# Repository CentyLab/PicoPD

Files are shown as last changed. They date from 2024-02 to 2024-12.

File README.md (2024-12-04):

# PicoPD
Pico PD is a development board for USB Power Delivery development with Raspberry Pi Pico footprint. The board can help you negotiate voltage from USB PD 2.0, 3.0, and 3.1 with PPS (programable power supply) up to 5A of current at 20V max. The board feature input current/voltage/temperture reading as well as power switch to cut of the current to external devices.

# Quick links
[AP33772 Library](https://github.com/CentyLab/AP33772-Cpp)

[PicoPD Pinout](#picopd-pinout)

[Setup for AP33772 objects](#setup-for-ap33772-objects)

[Basic AP33772 functions](#basic-ap33772-functions)

[Important note](#important-note)

[Arduino IDE setup](#arduino-ide-setup)

[VSCode PlatformIO setup](#vscode-platformio-setup)

[Enable Serial print for debugging](#enable-serial-debug)

# Pin out
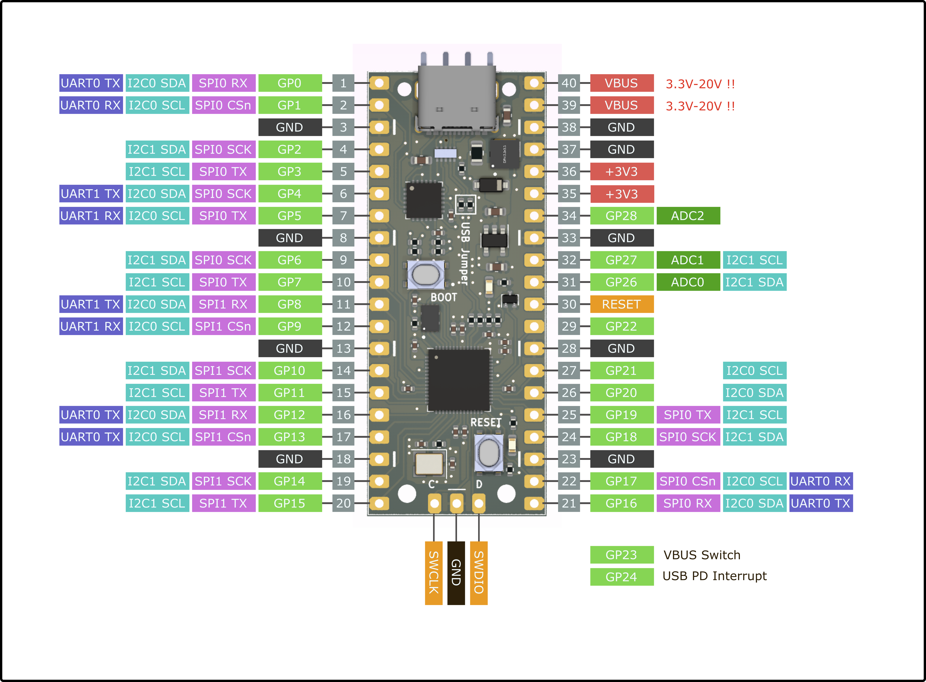
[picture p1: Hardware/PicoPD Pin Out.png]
pinout


# Setup for AP33772 objects
To use AP33772 IC with the library, first you need to create a `usbpd` object. Then set up your I2C pins and start collecting the power profiles from your charger. Ensure your delay after `Wire.begin()` is more than 500ms for stable PDOs request. Enable pin 23 to allow VBUS pass-through.
```
AP33772 usbpd; // Automatically wire to Wire0

void setup()
{
  Wire.setSDA(0); // Set the correct SDA0 pin
  Wire.setSCL(1); // Set the correct SCL0 pin
  Wire.begin();
  Serial.begin(115200);
  delay(1000); 		// Delay is needed for the IC to obtain PDOs
  usbpd.begin(); 	// Start pulling the PDOs from power supply

  pinMode(25, OUTPUT); // Built in LED
  pinMode(23, OUTPUT); // Load Switch
  digitalWrite(23, HIGH); // Turn on VBUS pin

  usbpd.printPDO(); //Print out PDO to Serial port
}
```

# Basic AP33772 functions
Common functions are:
```
setVoltage(int targetVoltage)       //Set voltage, unit in mV, read libary for logic flow
setMaxCurrent(int targetMaxCurrent) //Allow current limit if source has that capability
readVoltage()                       //Return voltage in mV
readCurrent()                       //Return current in mA
printPDO()                          //Print out PDOs in Serial
```

Set over tempearture protection
```
usbpd.setOTPTHR(100);               //Turn off output if NTC detect 100C or above
usbpd.setMask(OTP_EN);              //Enable Over Temp Protection flag
```

# Important note
After flashing, the latest AP33772-CPP has been updated to auto request PDO after bootup without reconnecting the charger. Thank to @Patronics contribution.

Calling `usbpd.printPDO()` without `Serial.begin()` can soft-brick your PicoPD. Causing the IC to be non-recognizable by your computer. You will have to use PicoProbe to reflash the chip. Check out @Patronics [PicoProbePCB](https://github.com/Patronics/PicoProbePCB) if you would like to make a stable fixture for firmware debugging.

# Enable Serial Debug

To enable Serial debug, there are 3 main methods:

**Using USB-C Power/Data splitter (easiest):** Use a USB-C Splitter that separates the USB 2.0 signal into another USB-C port. You only need USB 2.0 FullSpeed (12Mbps) for the job, but never hurts to get extra speed if needed later. 

* [USB-C Power/Data Splitter](https://lectronz.com/products/usb-c-splitter) (USB-HighSpeed)
* [USB-C PD Power Splitter](https://www.tindie.com/products/essenceeng/usb-c-pd-power-splitter/) (USB-HighSpeed)

**Using the provided solder pads at the back:** Desolder the front "USB Jumper" resistors. They are just 2x 0 Ohm resistors that bridge between the RP2040 IC and the USB-C port. Then use a [USB Type A Plug Breakout Cable](https://www.adafruit.com/product/4448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), or make your own from any USB cable and connect to the existing pad at the back of PicoPD

<p align="center">
  
</p>
<p align="center">
  
</p>

**Using UART communication**: Make sure you are not using GP0 and GP1 as they are reserved for I2C0 channel for AP33772 IC. Check out Youtube tutorial: [Talk to Your Pico Over Serial](https://www.youtube.com/watch?v=pbWhoJdYA1s)

# Arduino IDE setup
Open Arduino IDE, select File -> Preference
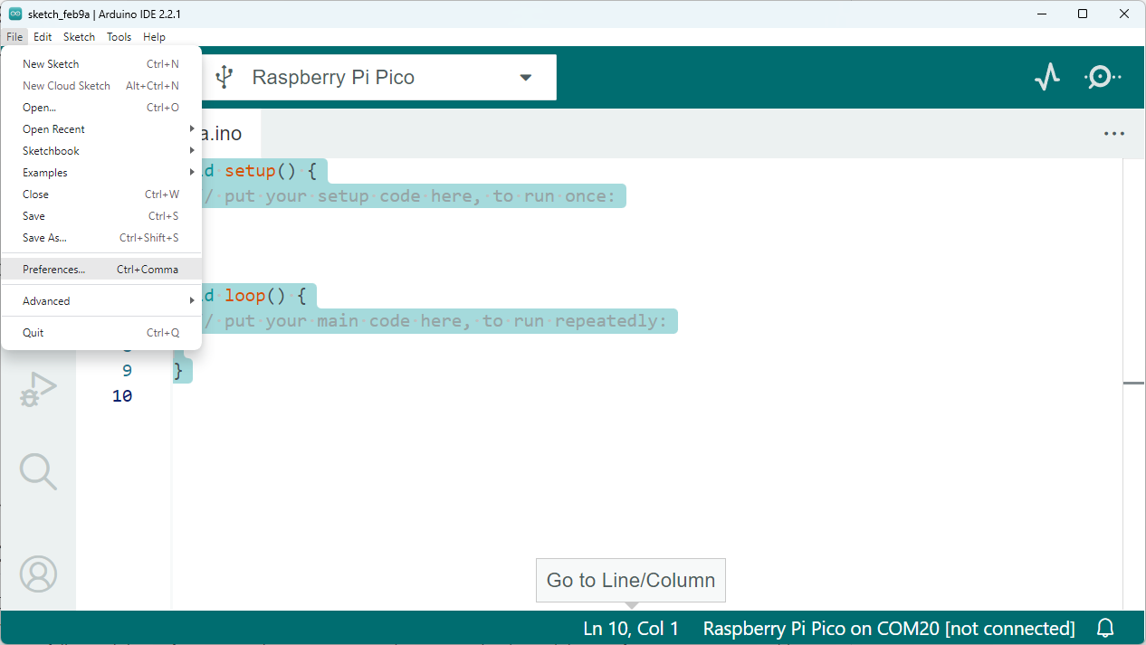
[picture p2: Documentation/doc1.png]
Preference


Copy this line below and place in "Aditional Boards Manager URLs" -> OK. This will allow you to pull the Earlephilhower Pico core that work with the AP33772 library.

```
https://github.com/earlephilhower/arduino-pico/releases/download/global/package_rp2040_index.json
```
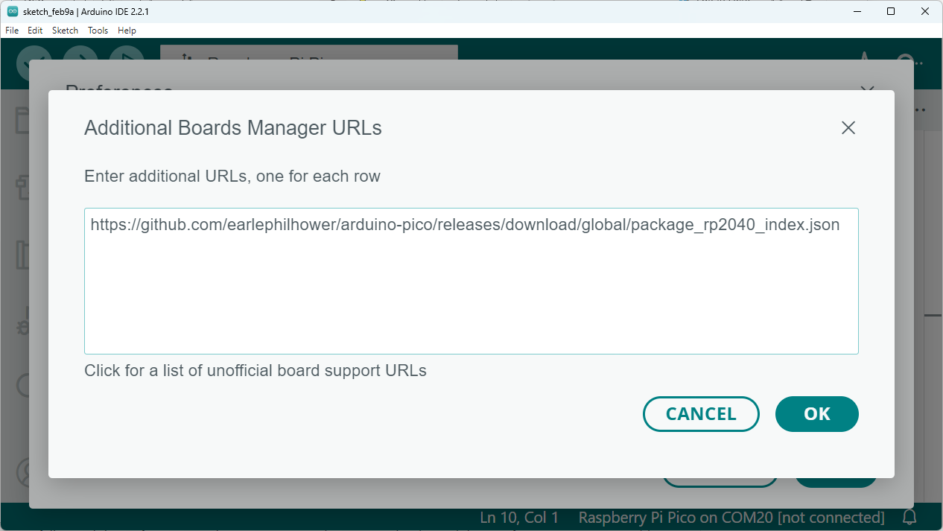
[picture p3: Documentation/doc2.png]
boardmanagerURL


From Board Manager, search for "Pico" and install the "Raspberry Pi Pico/RP2040" core by Earlephilhower

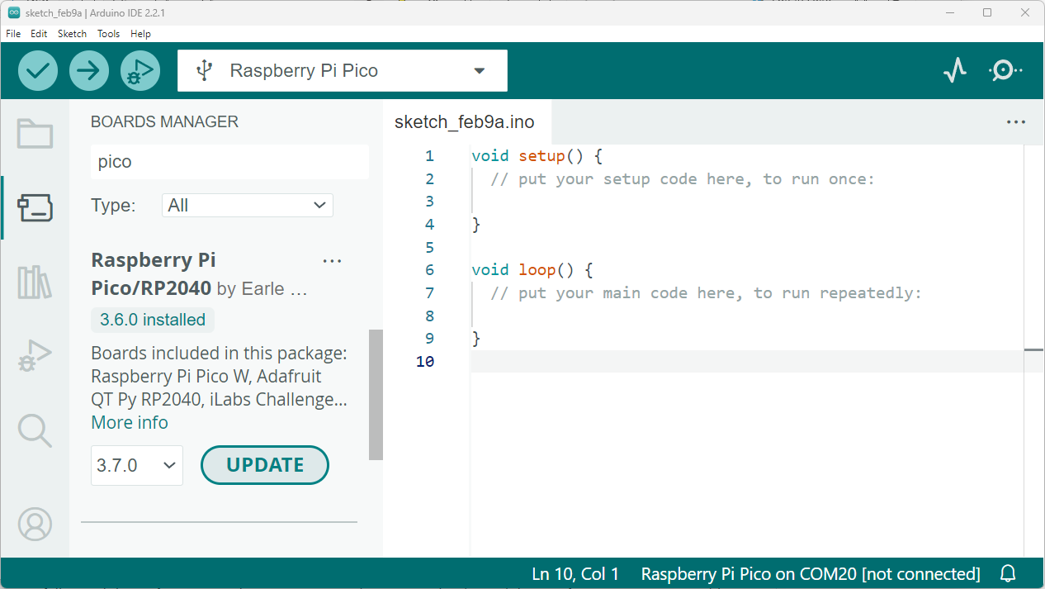
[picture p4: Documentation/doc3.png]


Now from Tool -> Board -> Raspberry Pi Pico/RP2040 -> Raspberry Pi Pico

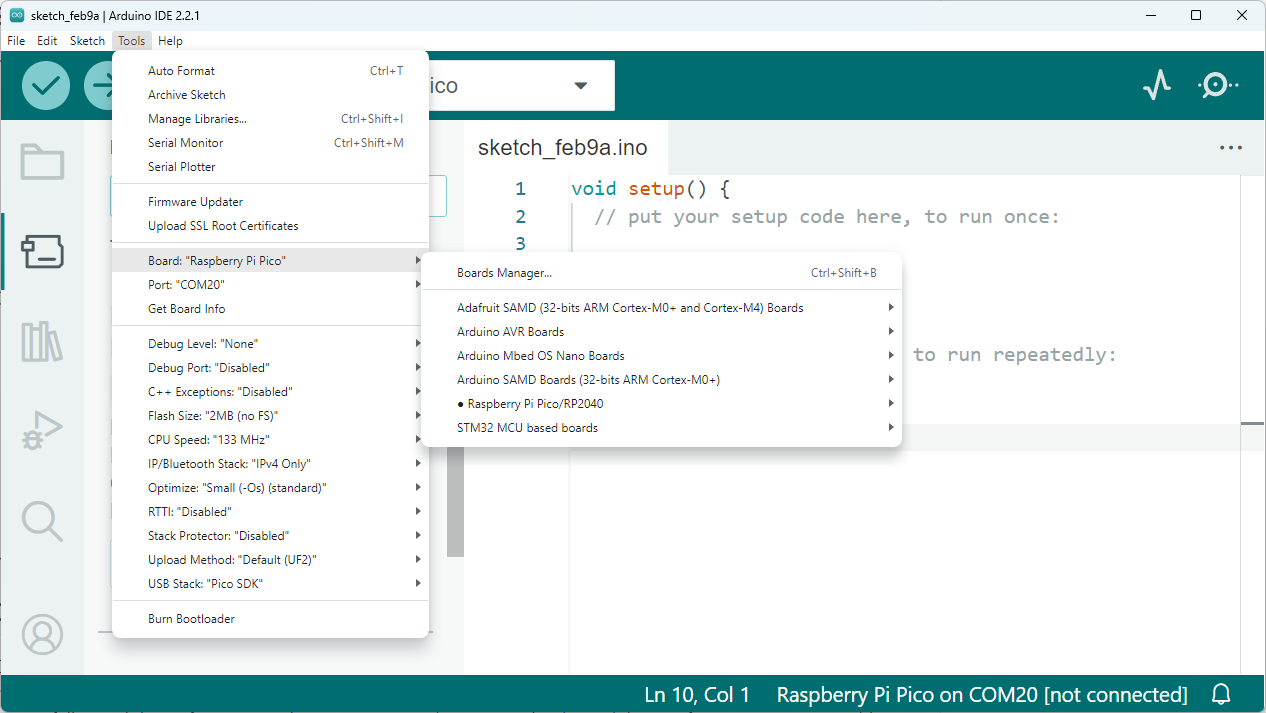
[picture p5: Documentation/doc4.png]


Now download the latest AP33772 library as a Zip file

```
https://github.com/CentyLab/AP33772-Cpp
```
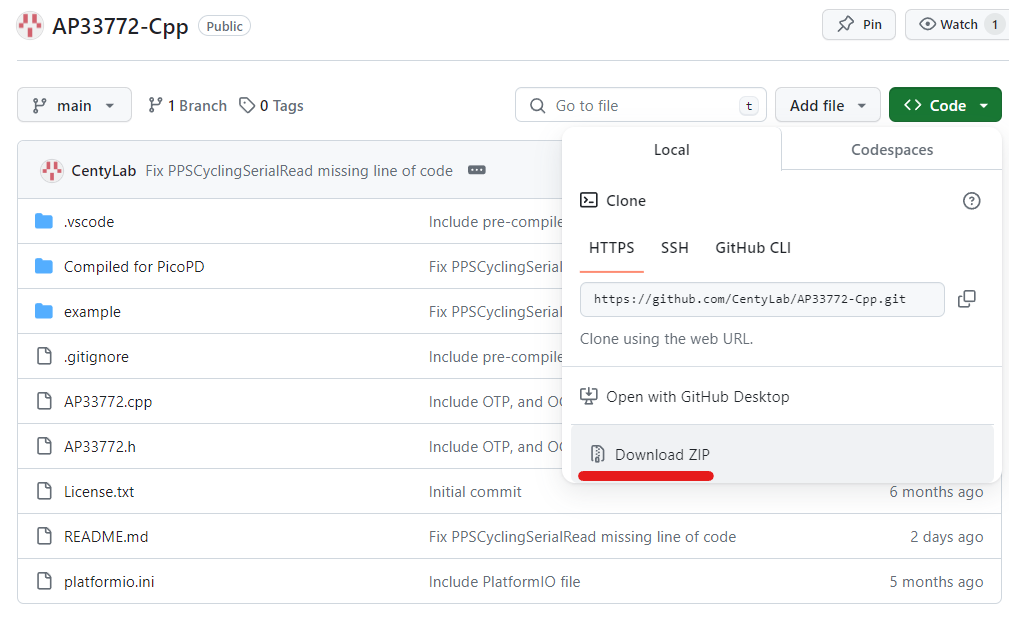
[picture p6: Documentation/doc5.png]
ap33772lib


Import the AP33772 library into your Arduino IDE. Sketch -> Include library -> Add .ZIP Library ...

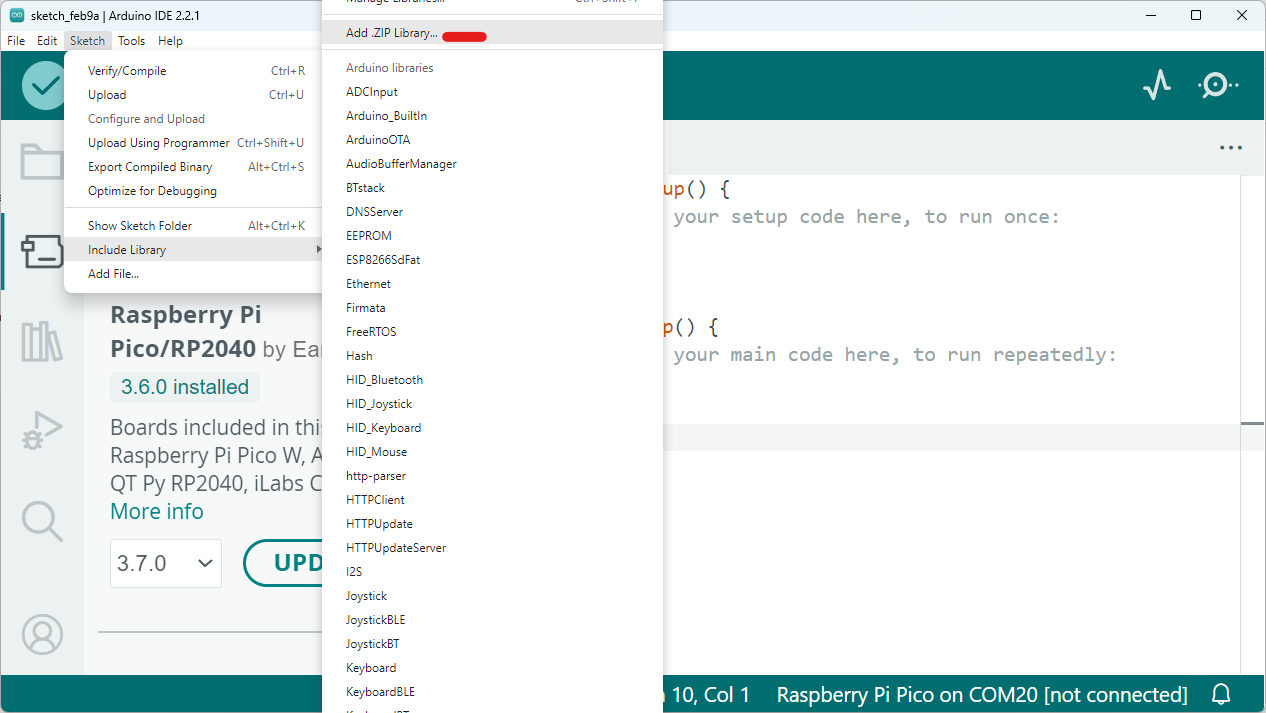
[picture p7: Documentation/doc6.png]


Now you start using the Example code in File -> Examples -> AP33772-Cpp-main. The example is ready to compile and flash on to your PicoPD.
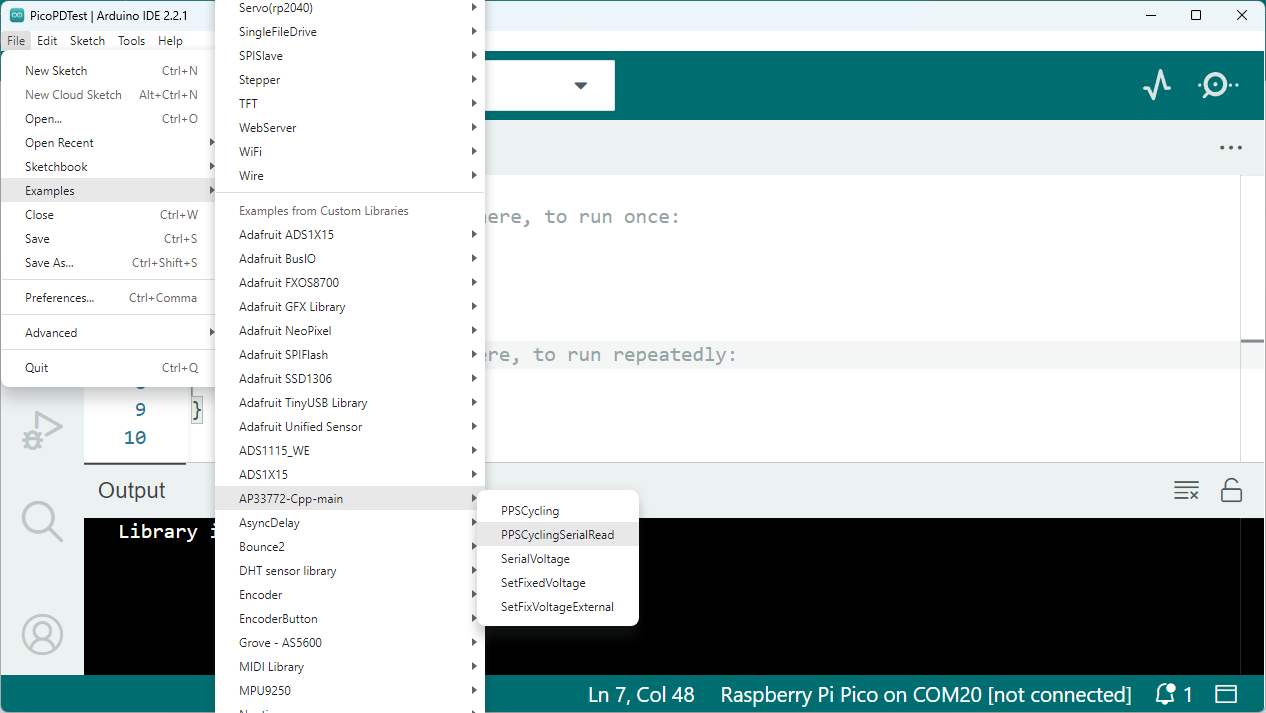
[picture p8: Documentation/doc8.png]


Now you can plug in your USB-C cable with Power Delivery 2.0/3.0/3.1. If you also like to have serial print out, check out [Enable Serial print for debugging](#enable-serial-debug).

# VSCode PlatformIO setup
After [VSCode](https://code.visualstudio.com/) installation, you will need to install PlatformIO extension.

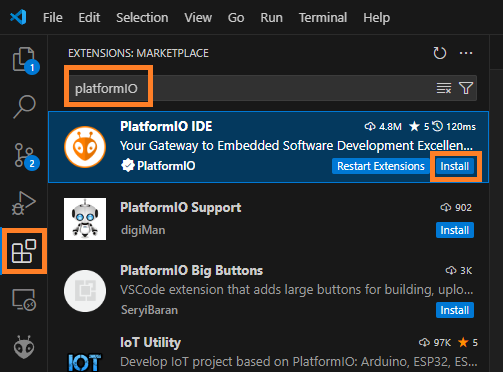
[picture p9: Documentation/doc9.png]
installplatform


Now create a new PlatformIO project
+ Name:WhatEverYouWantToCallit
+ Board: Pico (RasberryPi)
+ Framework: Arduino (default)

Click "Finish"

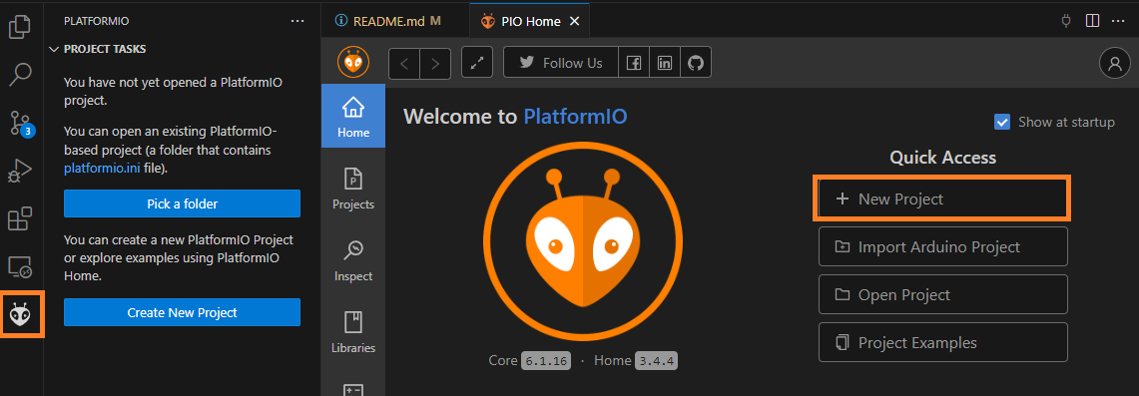
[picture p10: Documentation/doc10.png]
newproject


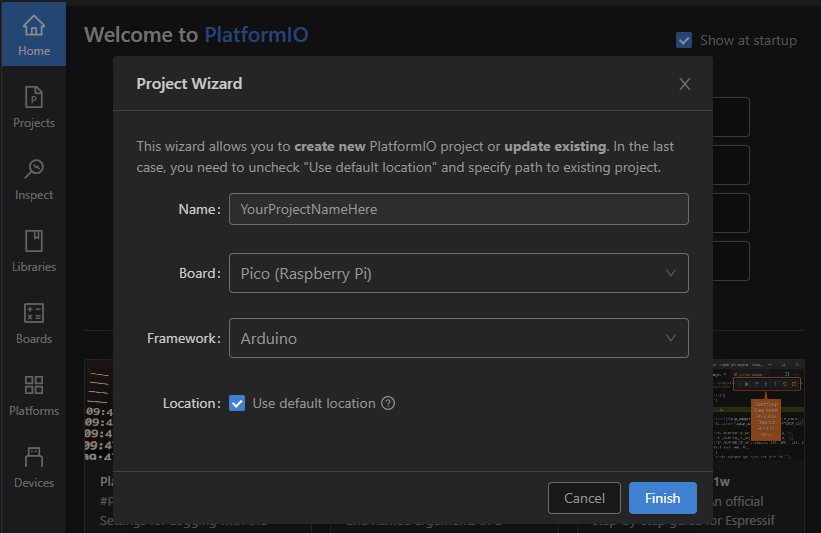
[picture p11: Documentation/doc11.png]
boardandframework


In your new project, copy this and replace everything in platformio.ini. This is how you ask PlatformIO to compile using Earlephilhower Pico core, and enable upload via USB.

```
[env:pico]
platform = https://github.com/maxgerhardt/platform-raspberrypi.git
board = pico
framework = arduino
board_build.core = earlephilhower

;; If directly upload from PC
upload_protocol = picotool
```

Now download the latest AP33772 library as a Zip file. Unzip and place the folder in `lib`

```
https://github.com/CentyLab/AP33772-Cpp
```

ap33772lib

Your lib folder should look like this

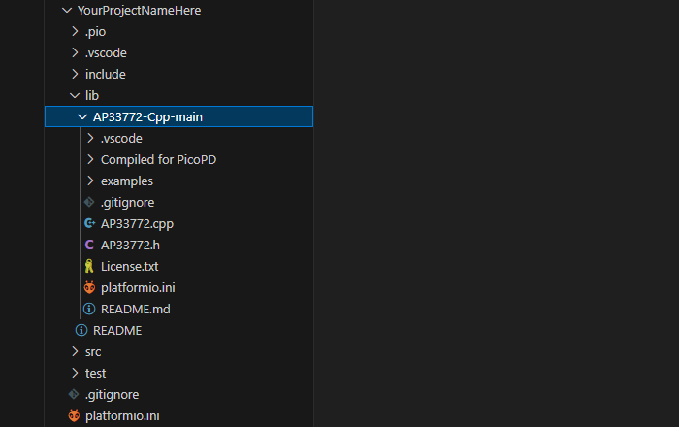
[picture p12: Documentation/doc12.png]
libstructur


To try out example code, you copy the content inside `lib/Compiled for PicoPD/PPSCycling/PPSCycling.ino`, And replace everything in your `src/main.cpp`

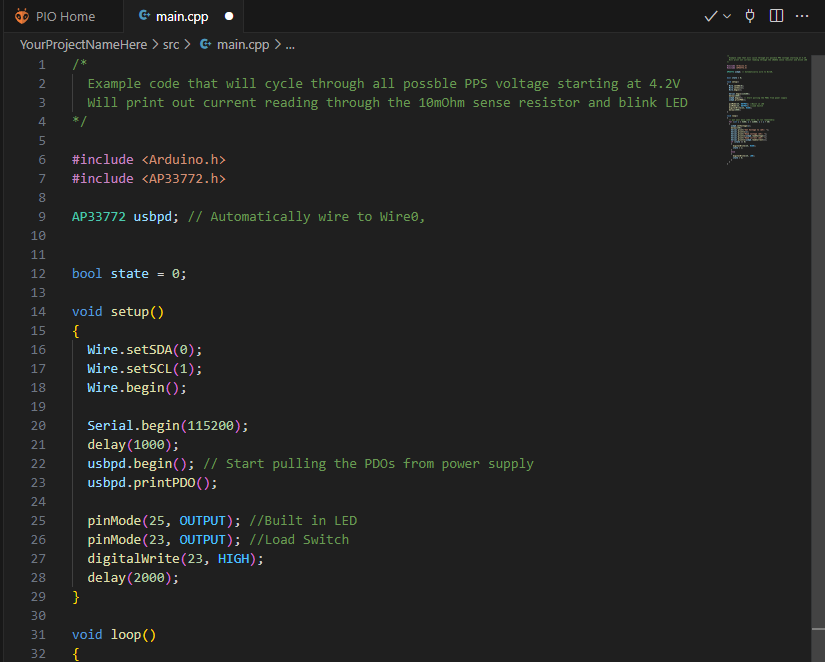
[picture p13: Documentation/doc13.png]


Now you can plug the PicoPD to your computer via USB-C and hit the upload button. After this, you will have to connect a charger to PicoPD to see the voltage cycling example. If you also like to have serial print out, check out [Enable Serial print for debugging](#enable-serial-debug).

maincpp

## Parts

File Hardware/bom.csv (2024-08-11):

Designator | Footprint | Quantity | Value | LCSC Part #
C10, C18, C2, C20, C21, C3, C4, C6, C7, C8, C9 | 0402 | 11 | 100nF | C1525
C11, C5 | 0402 | 2 | 2.2uF | C12530
C12 | 0603 | 1 | 1uF | C15849
C14 | 0603 | 1 | 2.2uF | C23630
C15, C22 | 0603 | 2 | 1u | C15849
C16, C17 | 0402 | 2 | 30pF | C1570
D1 | 0603 | 1 | RED | C2286
D2 | 0603 | 1 | GREEN | C72043
D3 | SON50P100X255X50-10N | 1 | TPD4E05U06DQAR | C138714
D4 | D_SOD-123 | 1 | D | C8598
J2 | YTC-TC16S-28 | 1 | USB_C_Receptacle | C2927293
Q2 | SOT-416 | 1 | DTC143EETL | C2991940
Q3 | TRANS_AON7403 | 1 | MSK3419DF | C2902915
R1, R16, R3, R4, R7 | 0402 | 5 | 5.1k | C25905
R10, R11 | 0402 | 2 | 27R | C138021
R12, R6 | 0402 | 2 | 10k | C25744
R13, R14, R17, R2 | 0402 | 4 | 1k | C11702
R18, R19 | 0402 | 2 | 0R | C17168
R5 | 0805 | 1 | 10mR | C728271
SW2 | SW_PTS810_SJM_250_SMTR_LFS | 1 | SW_RESET | C221896
SW4 | SW_PTS810_SJM_250_SMTR_LFS | 1 | SW_BOOT | C221896
TH1 | 0402 | 1 | Thermistor_NTC | C77131
U1 | QFN-24-1EP_4x4mm_P0.5mm_EP2.6x2.6mm | 1 | AP33772 | C5244513
U2 | IC_W25Q16JVUXIQ_TR | 1 | W25Q16JVUXIQ_TR | C2843335
U3 | QFN-56-1EP_7x7mm_P0.4mm_EP3.2x3.2mm | 1 | RP2040 | C2040
U4 | SOT-23-5 | 1 | AP2204K-3.3 | C112032
Y1 | Crystal_SMD_3225-4Pin_3.2x2.5mm | 1 | 12MHz | C133334

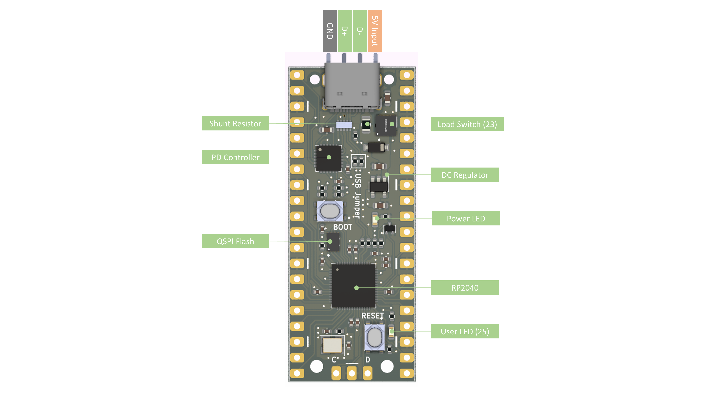
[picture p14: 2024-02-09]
Hardware/PicoPD Component Note.png

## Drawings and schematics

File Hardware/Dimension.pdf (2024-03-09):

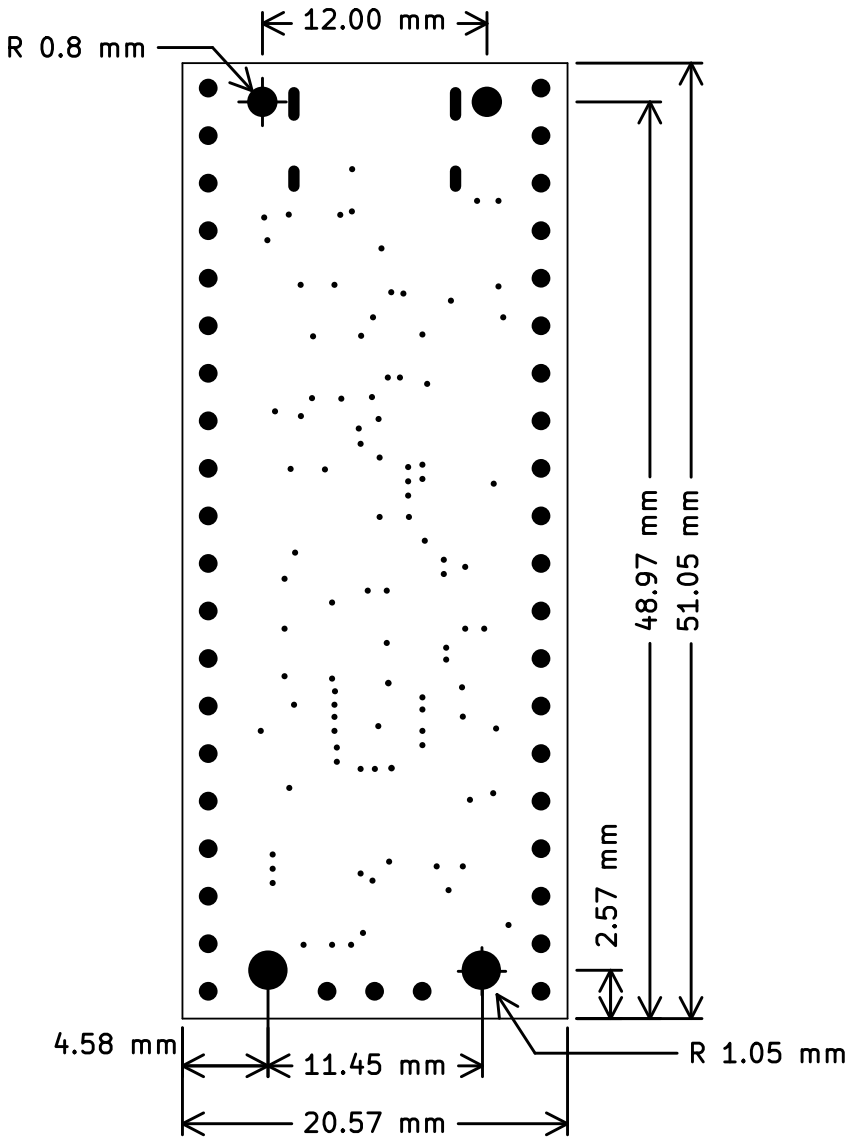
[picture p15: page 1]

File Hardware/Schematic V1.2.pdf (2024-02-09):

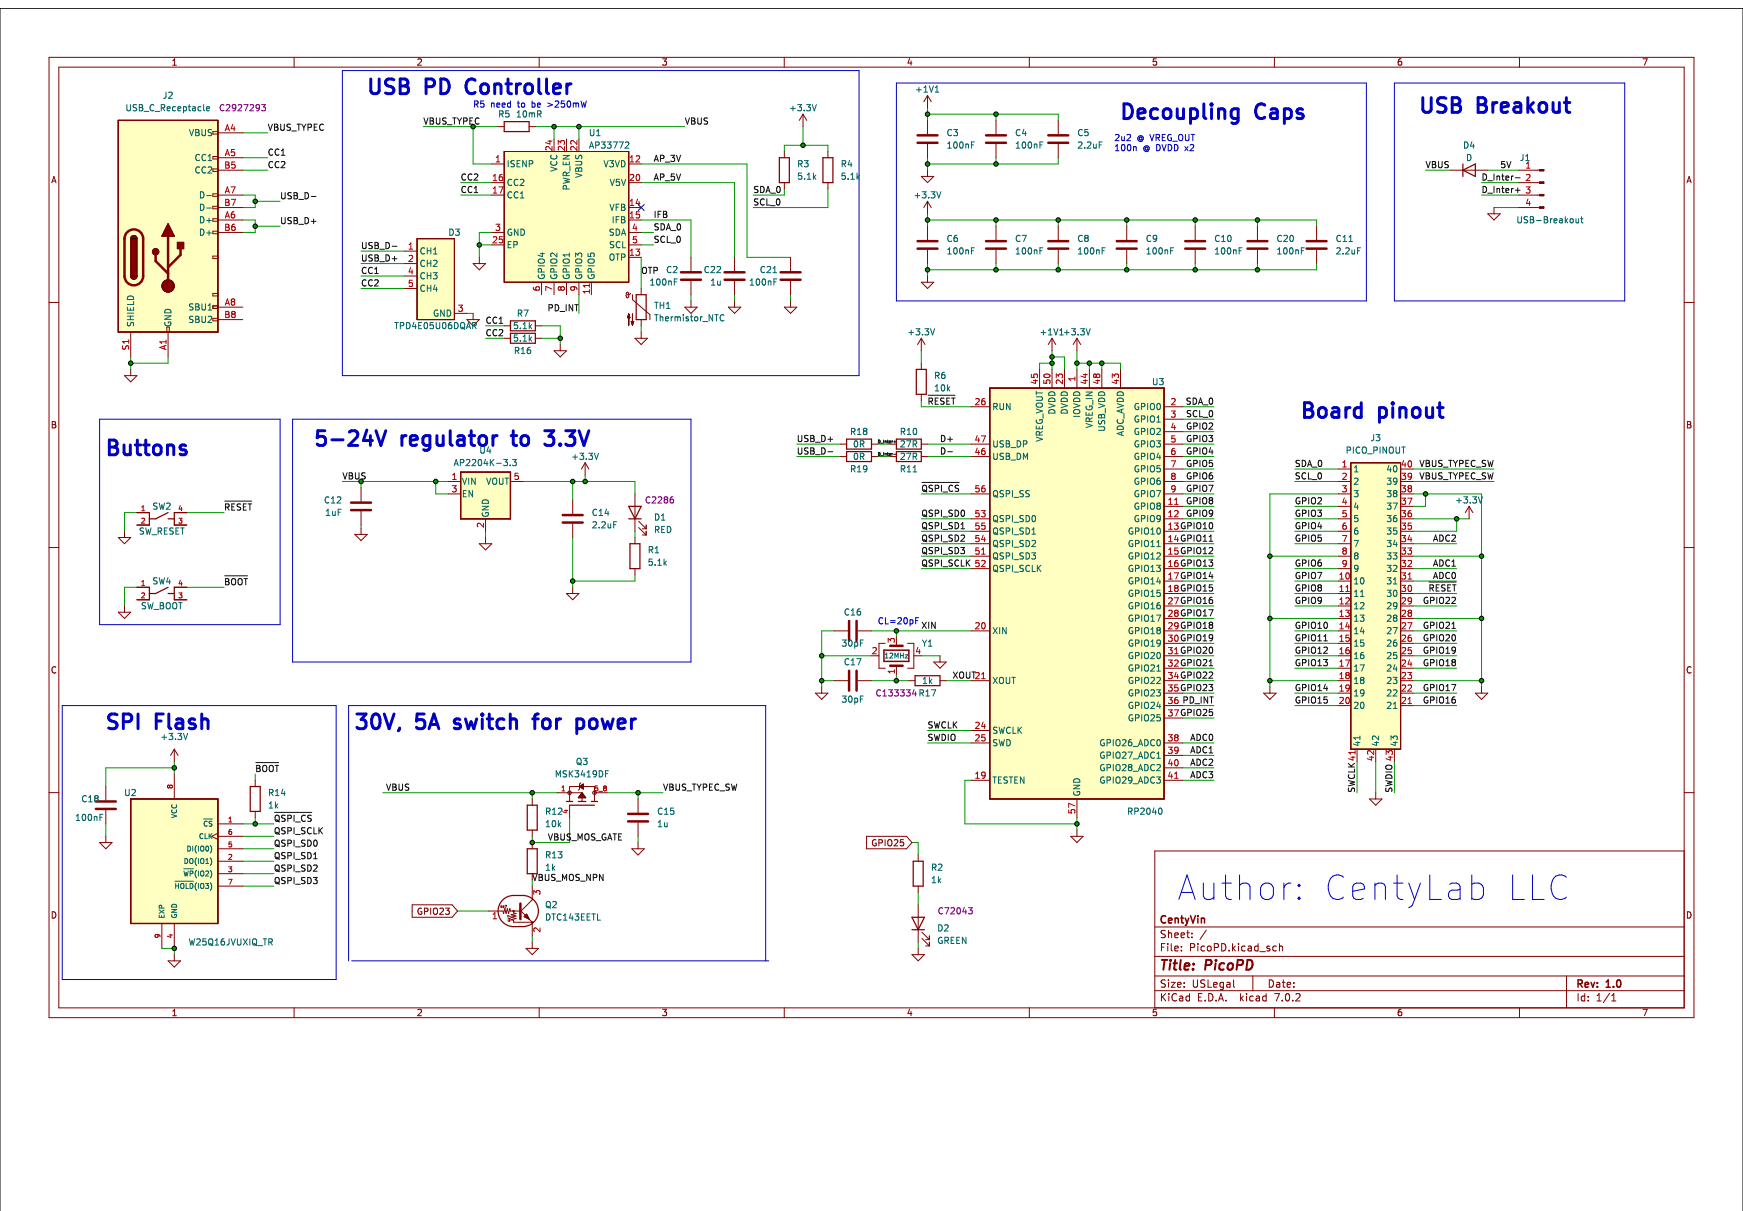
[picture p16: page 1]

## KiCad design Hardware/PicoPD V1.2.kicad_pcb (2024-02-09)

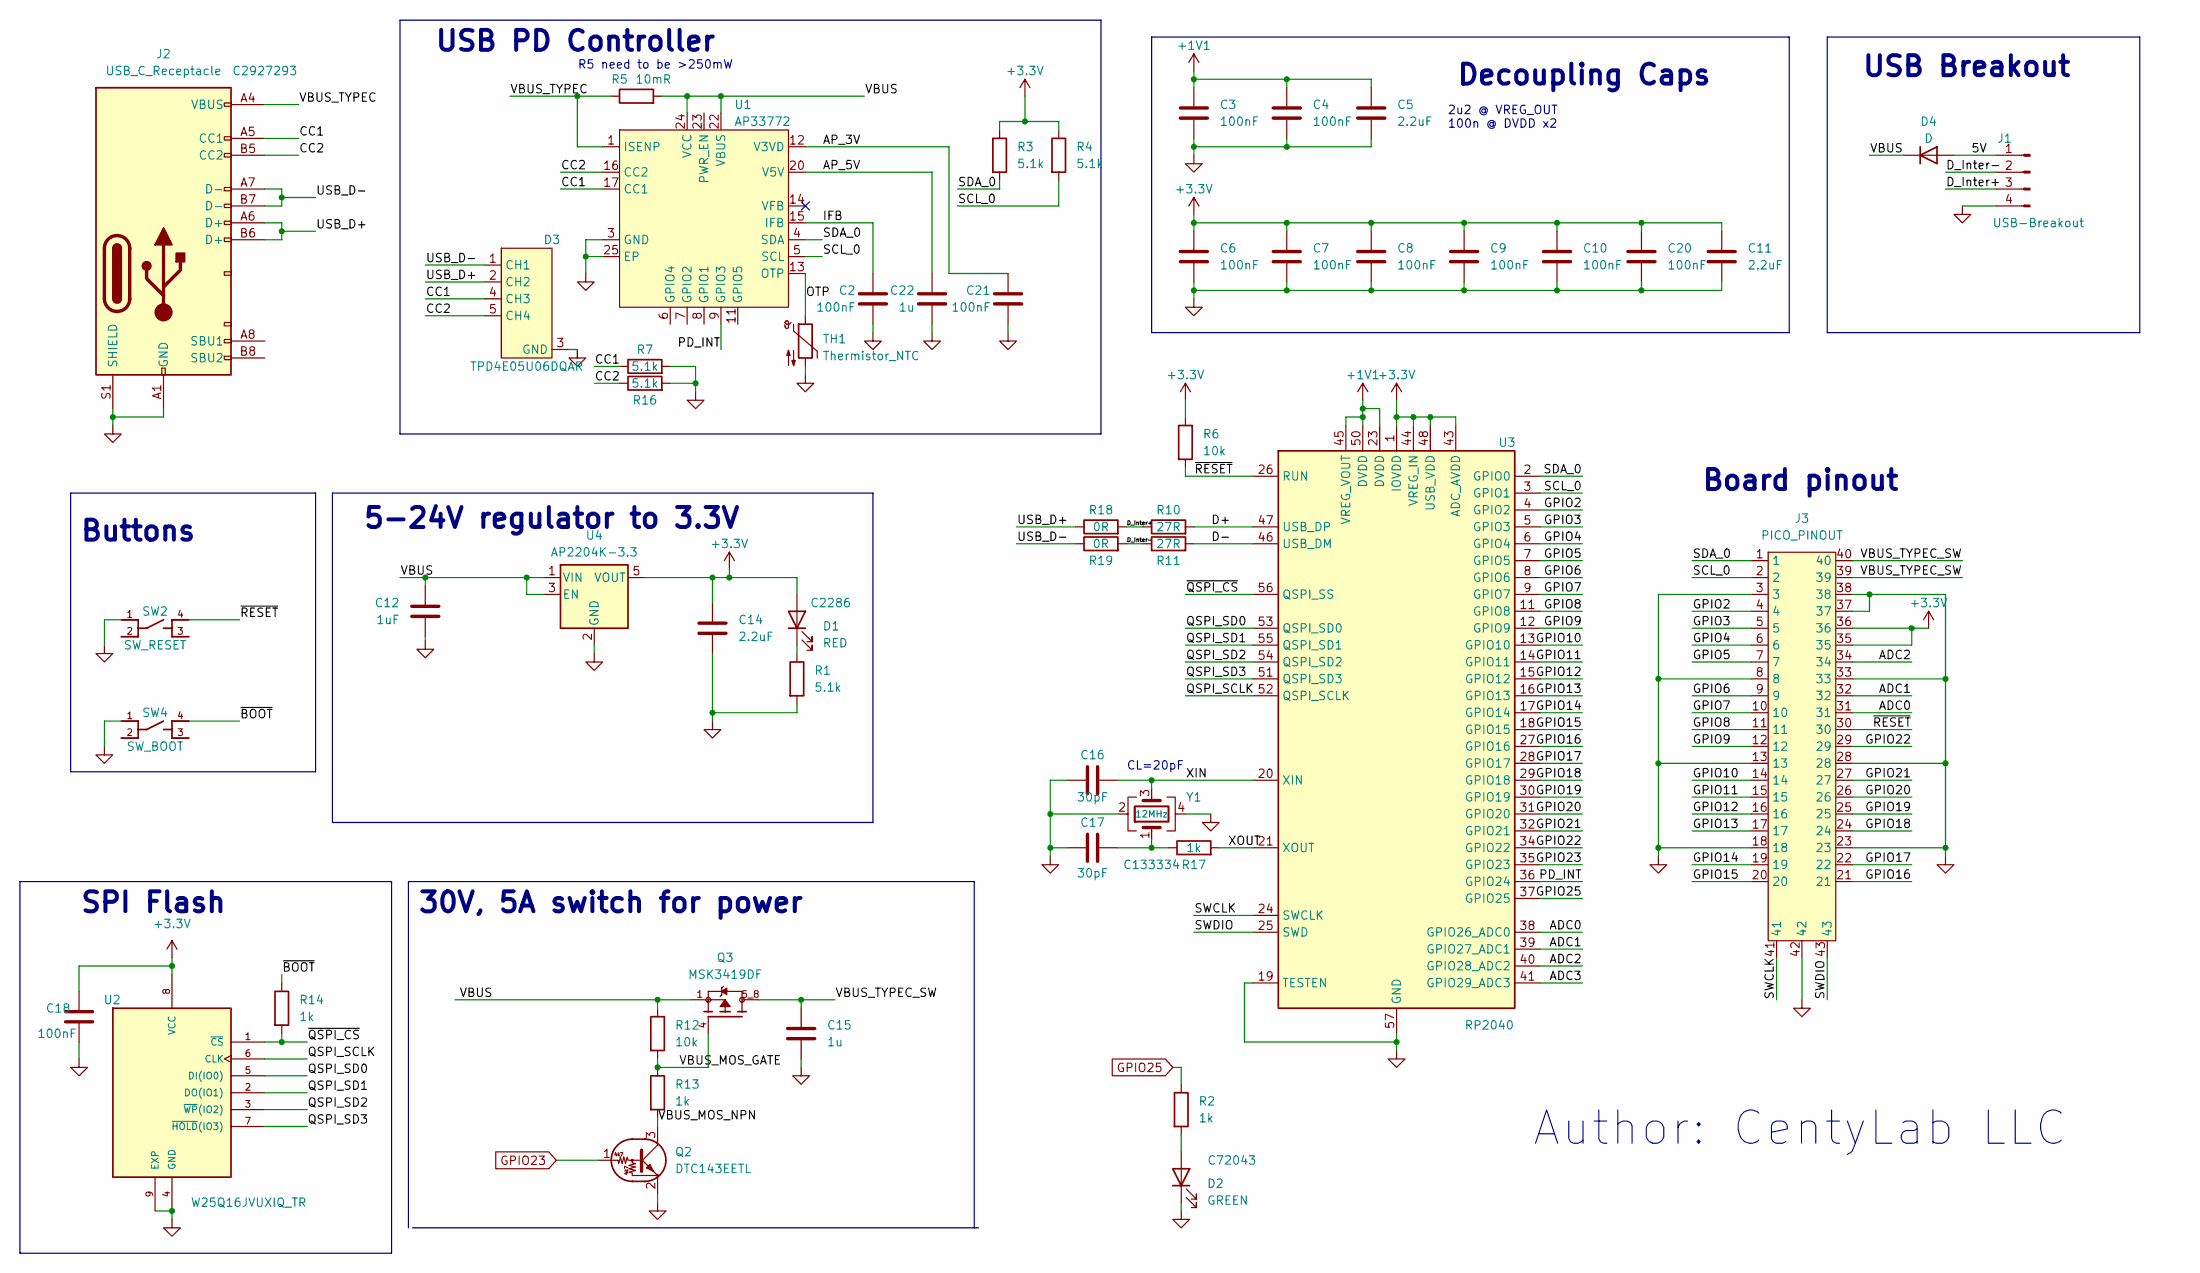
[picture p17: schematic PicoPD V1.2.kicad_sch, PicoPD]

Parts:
C2, C3, C4, C6, C7, C8, C9, C10, C18, C20, C21: 100nF; C_0402_1005Metric; LCSC C1525
C5, C11: 2.2uF; C_0402_1005Metric; LCSC C12530
C12: 1uF; C_0603_1608Metric; Voltage 50V; LCSC C15849
C14: 2.2uF; C_0603_1608Metric; Voltage 16V; LCSC C23630
C15, C22: 1u; C_0603_1608Metric; LCSC C15849
C16, C17: 30pF; C_0402_1005Metric; LCSC C1570
D1: RED; LED_0603_1608Metric; LCSC C2286
D2: GREEN; LED_0603_1608Metric; LCSC C72043
D3: TPD4E05U06DQAR; SON50P100X255X50-10N; LCSCAlternative1 C478014
D4: D; D_SOD-123; LCSC C8598
J1: USB-Breakout; 1x4_2.54mmHorizontalSMD
J2: USB_C_Receptacle; YTC-TC16S-28; LCSC C2927293
J3: PICO_PINOUT; PICO_Thru
Q2: DTC143EETL; SOT-416; LCSC C2991940
Q3: MSK3419DF; TRANS_AON7403; PARTREV G; LCSC C2902915
R1, R3, R4, R7, R16: 5.1k; R_0402_1005Metric; LCSC C25905
R2, R13, R14, R17: 1k; R_0402_1005Metric; LCSC C11702
R5: 10mR; R_0805_2012Metric; LCSC C728271
R6, R12: 10k; R_0402_1005Metric; LCSC C25744
R10, R11: 27R; R_0402_1005Metric; LCSC C138021
R18, R19: 0R; R_0402_1005Metric; LCSC C17168
SW2: SW_RESET; SW_PTS810_SJM_250_SMTR_LFS; LCSC C221896
SW4: SW_BOOT; SW_PTS810_SJM_250_SMTR_LFS; LCSC C221896
TH1: Thermistor_NTC; R_0402_1005Metric; LCSC C77131
U1: AP33772; QFN-24-1EP_4x4mm_P0.5mm_EP2.6x2.6mm
U2: W25Q16JVUXIQ_TR; IC_W25Q16JVUXIQ_TR; PARTREV H; LCSC C2843335
U3: RP2040; QFN-56-1EP_7x7mm_P0.4mm_EP3.2x3.2mm; LCSC C2040
U4: AP2204K-3.3; SOT-23-5; JLCPCB Rotation Offset 180
Y1: 12MHz; Crystal_SMD_3225-4Pin_3.2x2.5mm; LCSC C133334

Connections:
+1V1: C3.1, C4.1, C5.1, U3.23 (DVDD), U3.45 (VREG_VOUT), U3.50 (DVDD)
+3.3V: C6.1, C7.1, C8.1, C9.1, C10.1, C11.1, C14.1, C18.1, C20.1, D1.2 (A), J3.35, J3.36, R3.1, R4.1, R6.1, U2.8 (VCC), U3.1 (IOVDD), U3.10 (IOVDD), U3.22 (IOVDD), U3.33 (IOVDD), U3.42 (IOVDD), U3.43 (ADC_AVDD), U3.44 (VREG_IN), U3.48 (USB_VDD), U3.49 (IOVDD), U4.5 (VOUT)
/5V: D4.2 (A), J1.1
/ADC0: J3.31, U3.38 (GPIO26_ADC0)
/ADC1: J3.32, U3.39 (GPIO27_ADC1)
/ADC2: J3.34, U3.40 (GPIO28_ADC2)
/ADC3: U3.41 (GPIO29_ADC3)
/AP_3V: C21.1, U1.12 (V3VD)
/AP_5V: C22.1, U1.20 (V5V)
/CC1: D3.4 (CH3), D3.7, J2.A5 (CC1), R7.1, U1.17 (CC1)
/CC2: D3.5 (CH4), D3.6, J2.B5 (CC2), R16.1, U1.16 (CC2)
/D+: R10.2, U3.47 (USB_DP)
/D-: R11.2, U3.46 (USB_DM)
/D_Inter+: J1.3, R10.1, R18.2
/D_Inter-: J1.2, R11.1, R19.2
/GPIO2: J3.4, U3.4 (GPIO2)
/GPIO3: J3.5, U3.5 (GPIO3)
/GPIO4: J3.6, U3.6 (GPIO4)
/GPIO5: J3.7, U3.7 (GPIO5)
/GPIO6: J3.9, U3.8 (GPIO6)
/GPIO7: J3.10, U3.9 (GPIO7)
/GPIO8: J3.11, U3.11 (GPIO8)
/GPIO9: J3.12, U3.12 (GPIO9)
/GPIO10: J3.14, U3.13 (GPIO10)
/GPIO11: J3.15, U3.14 (GPIO11)
/GPIO12: J3.16, U3.15 (GPIO12)
/GPIO13: J3.17, U3.16 (GPIO13)
/GPIO14: J3.19, U3.17 (GPIO14)
/GPIO15: J3.20, U3.18 (GPIO15)
/GPIO16: J3.21, U3.27 (GPIO16)
/GPIO17: J3.22, U3.28 (GPIO17)
/GPIO18: J3.24, U3.29 (GPIO18)
/GPIO19: J3.25, U3.30 (GPIO19)
/GPIO20: J3.26, U3.31 (GPIO20)
/GPIO21: J3.27, U3.32 (GPIO21)
/GPIO22: J3.29, U3.34 (GPIO22)
/IFB: C2.1, U1.15 (IFB)
/OTP: TH1.1, U1.13 (OTP)
/PD_INT: U1.9 (GPIO3), U3.36 (GPIO24)
/QSPI_SCLK: U2.6 (CLK), U3.52 (QSPI_SCLK)
/QSPI_SD0: U2.5 (DI(IO0)), U3.53 (QSPI_SD0)
/QSPI_SD1: U2.2 (DO(IO1)), U3.55 (QSPI_SD1)
/QSPI_SD2: U2.3 (~WP(IO2)), U3.54 (QSPI_SD2)
/QSPI_SD3: U2.7 (~HOLD(IO3)), U3.51 (QSPI_SD3)
/SCL_0: J3.2, R4.2, U1.5 (SCL), U3.3 (GPIO1)
/SDA_0: J3.1, R3.2, U1.4 (SDA), U3.2 (GPIO0)
/SWCLK: J3.41, U3.24 (SWCLK)
/SWDIO: J3.43, U3.25 (SWD)
/USB_D+: D3.2 (CH2), D3.9, J2.A6 (D+), J2.B6 (D+), R18.1
/USB_D-: D3.1 (CH1), D3.10, J2.A7 (D-), J2.B7 (D-), R19.1
/VBUS: C12.2, D4.1 (K), Q3.1, Q3.2, Q3.3, R5.2, R12.1, U1.22 (VBUS), U1.24 (VCC), U4.1 (VIN), U4.3 (EN)
/VBUS_MOS_GATE: Q3.4, R12.2, R13.1
/VBUS_MOS_NPN: Q2.3 (C), R13.2
/VBUS_TYPEC: J2.A4 (VBUS), J2.A9 (VBUS), J2.B4 (VBUS), J2.B9 (VBUS), R5.1, U1.1 (ISENP)
/VBUS_TYPEC_SW: C15.1, J3.39, J3.40, Q3.5_8
/XIN: C16.1, U3.20 (XIN), Y1.3
/XOUT: R17.2, U3.21 (XOUT)
/~BOOT: R14.1, SW4.4
/~QSPI_CS: R14.2, U2.1 (~CS), U3.56 (QSPI_SS)
/~RESET: J3.30, R6.2, SW2.4, U3.26 (RUN)
GND: C2.2, C3.2, C4.2, C5.2, C6.2, C7.2, C8.2, C9.2, C10.2, C11.2, C12.1, C14.2, C15.2, C16.2, C17.2, C18.2, C20.2, C21.2, C22.2, D2.1 (K), D3.3 (GND), D3.8 (GND), J1.4, J2.A1 (GND), J2.A12 (GND), J2.B1 (GND), J2.B12 (GND), J2.S1 (SHIELD), J3.3, J3.8, J3.13, J3.18, J3.23, J3.28, J3.33, J3.37, J3.38, J3.42, Q2.2 (E), R1.2, R7.2, R16.2, SW2.1, SW4.1, TH1.2, U1.3 (GND), U1.25 (EP), U2.4 (GND), U2.9 (EXP), U3.19 (TESTEN), U3.57 (GND), U4.2 (GND), Y1.2, Y1.4
GPIO23: Q2.1 (B), U3.35 (GPIO23)
GPIO25: R2.1, U3.37 (GPIO25)
unnamed: C17.1, R17.1, Y1.1
unnamed: D1.1 (K), R1.1
unnamed: D2.2 (A), R2.2
unnamed: U1.2 (NC), U1.10 (NC), U1.18 (NC), U1.19 (NC), U1.21 (NC)

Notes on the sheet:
USB PD Controller
2u2 @ VREG_OUT 100n @ DVDD x2
30V, 5A switch for power
USB Breakout
CL=20pF
Author: CentyLab LLC
Buttons
Decoupling Caps
5-24V regulator to 3.3V
SPI Flash
Board pinout
R5 need to be >250mW

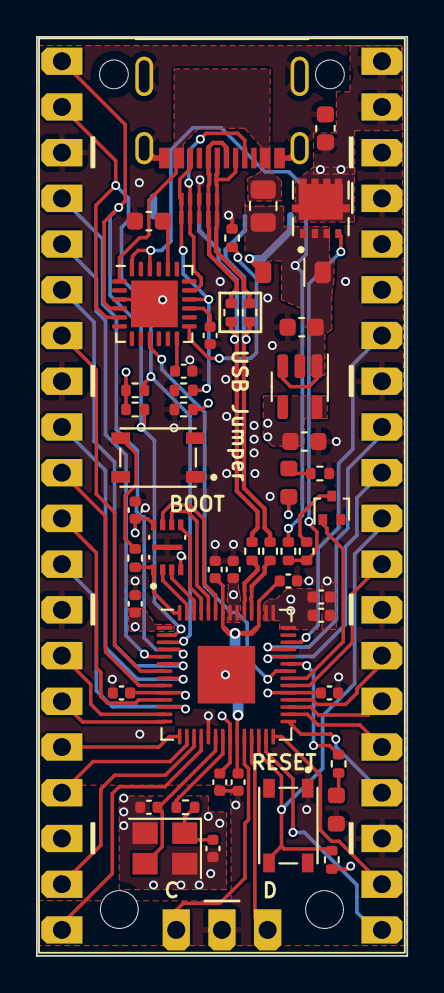
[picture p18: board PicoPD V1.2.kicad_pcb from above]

Board: 4 copper layers, 20.6 x 51.1 mm, 52 parts (1 on the bottom side), 66 nets.

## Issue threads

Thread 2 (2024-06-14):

PPS chargers that support current control.

ysuito, 2024-06-14:
I purchased this product at Elecrow. Thank you for providing a very good product.
I would like to limit the current value with setMaxCurrent(), can you tell me which PPS chargers you know that support current control?

CentyLab, 2024-06-14:
You should check out UGREEN Nexode 140W. This will give you 3.3-21V 5A, max
what pps can do.

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

ysuito, 2024-06-14:
Thank you for your response! I will check it out.

CentyLab, 2024-06-14:
Also check this list that I have:

[UGREEN 100W Nexode Pro](https://www.amazon.com/UGREEN-Charger-Compact-MacBook-Pixelbook/dp/B0CCVQB7MY/) - PPS 3.3-21.0 @ 5A
[UGREEN 100W](https://www.amazon.com/UGREEN-100W-USB-Multiport-Charger/dp/B091Z6JNX4) - PPS 3.3 - 21.0 @ 3A
[UGREEN 140W](https://www.amazon.com/UGREEN-Charger-Nexode-Compatible-MacBook/dp/B0B129DM9T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) - PPS 3.3 - 21.0 @ 5A
[AOHI Magcube 140W](https://www.amazon.com/AOHI-Magcube-Charger-MacBook-Foldable/dp/B0C4GWH7KL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) - PPS 3.3 - 21.0 @ 5A
[GKUTW HX65P3 65W](https://www.amazon.com/dp/B0CJJL3WLK?th=1) - PPS 3.3 - 21 @ 3A
[Anker 737 (GaN Prime 120W)](https://www.amazon.com/Anker-Charger-GaNPrime-Compact-Foldable/dp/B09W2N774C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) - PPS 3.3 - 11.0 @ 3A
[Anker 737 Power Bank](https://www.amazon.com/Anker-PowerCore-Portable-Charger-Compatible/dp/B09VPHVT2Z?ref_=ast_sto_dp&th=1) - PPS 3.3 - 21.0 @ 5A
[Anker PowerHouse 521](https://www.anker.com/products/a1720?variant=41982439686294) - PPS 3.3 - 11.0 @ 3A

Closed 2024-06-14.

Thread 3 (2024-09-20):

AP33772 NRND.

mhanuel26, 2024-09-20:
Hi,

I am looking at your hw design and noticed that AP33772S is recommended instead of AP33772, I need to check at differences , just wondering which IC your design uses?

Thanks for this great project.

CentyLab, 2024-09-20:
hi, this device use ap33772. At the time of development, AP33772S was not
out yet. I don think you can even buy it right now.

On Fri, Sep 20, 2024, 2:45 AM Manuel Iglesias Abbatemarco <
***@***.***> wrote:

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

Closed 2024-09-22.

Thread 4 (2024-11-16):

Going from 4.5V to 3.5V does not fully update the request voltage

CentyLab, 2024-11-16:
Turning the knob with 1V unit at 3.6V screen will show target 3.3V. However, the output voltage will stay at 3.6V.

Seem like the target is rounded to 3.3V after going under but doesn't send this request to the PD charger.

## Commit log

2024-02-09 Update documentation
    [PicoPD V1.2.kicad_pcb, PicoPD V1.2.kicad_sch]
2024-08-11 Added BOM and Pick-N-Place
    [bom.csv, positions.csv]
